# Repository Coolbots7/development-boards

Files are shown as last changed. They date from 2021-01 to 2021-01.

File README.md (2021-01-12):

# Development Boards
PCBs made to test core designs and / or help with rapid prototyping.

# Boards
## ATMega32u4 Development Board (Arduino Micro Equivalent)
Breadboard breakout PCB for an ATMega32u4 8-bit AVR microcontroller.

<p float="left">
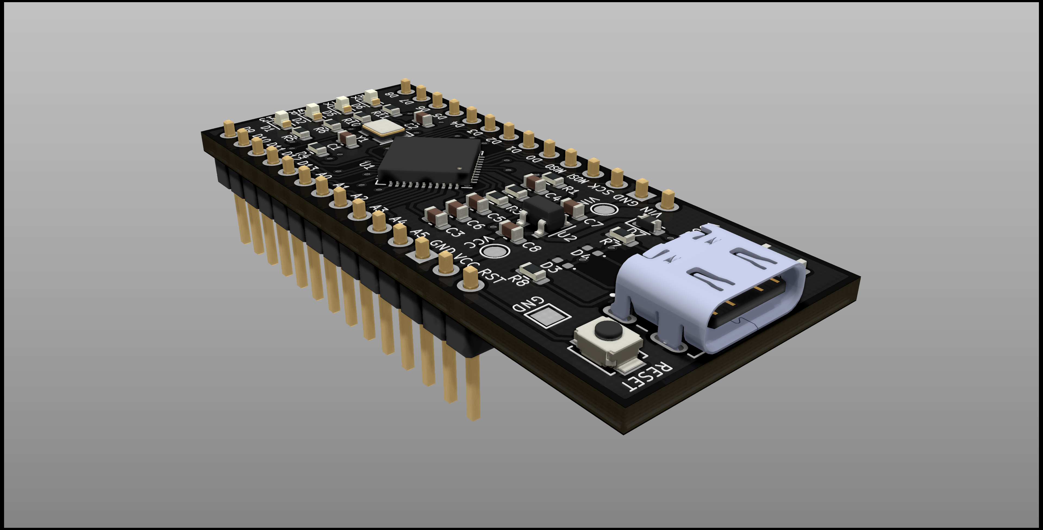
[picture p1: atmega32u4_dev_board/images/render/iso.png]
iso render
 
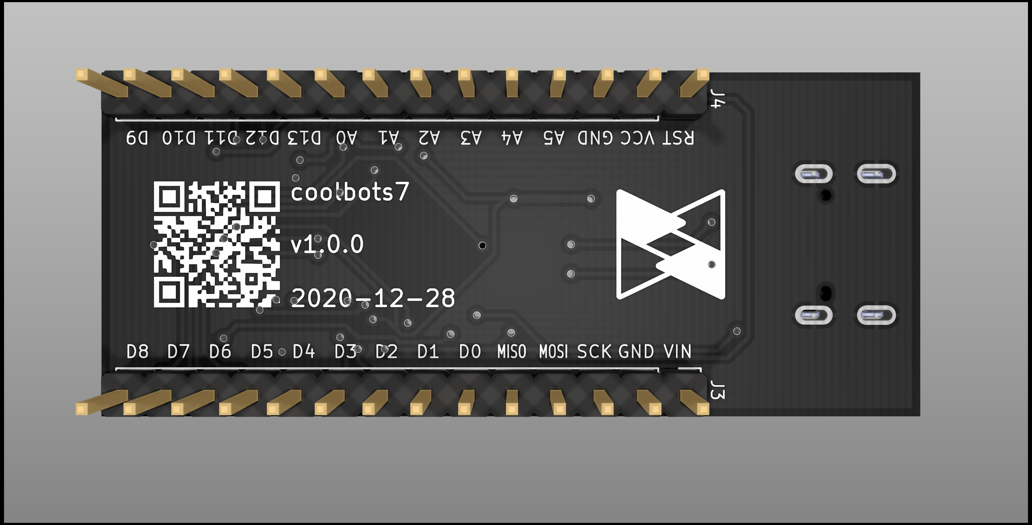
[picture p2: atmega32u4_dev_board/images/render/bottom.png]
bottom render
 
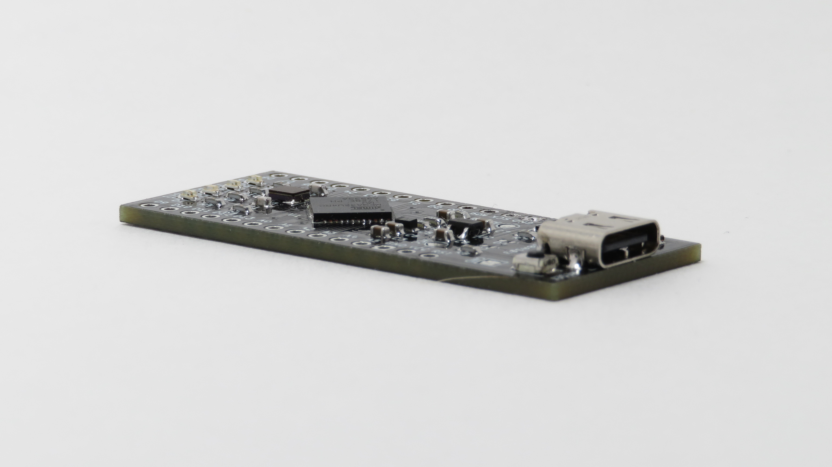
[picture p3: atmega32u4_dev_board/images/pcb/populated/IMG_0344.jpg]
iso populated
 
</p>

### Features:
* USB-C connector for programming and power up to 250mA.
* 5V 500mA linear regulator for external power up to 12VDC.
* Power, TX, RX, and D13 LEDs.
* Pins are labeled on both the top and bottom of the board for easy reference.
  * Note: The pinout is not the same as an actual Arduino Micro

### Bill of Materials:
[Shopping Cart on DigiKey](https://www.digikey.com/short/4ch5mv)

### Future Ideas:
* Ability to construct 3.3V and 5V versions using the same PCB

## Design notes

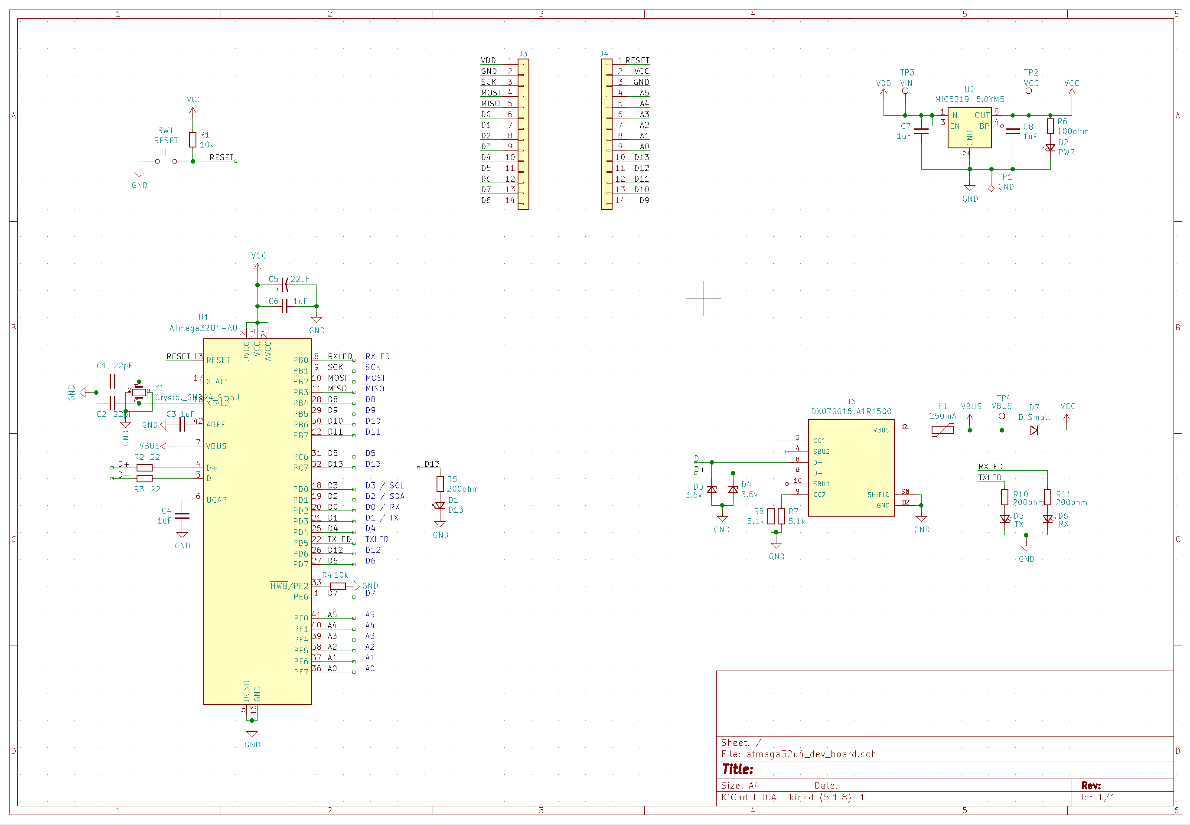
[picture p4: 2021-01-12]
atmega32u4_dev_board/images/schematic/schematic.png

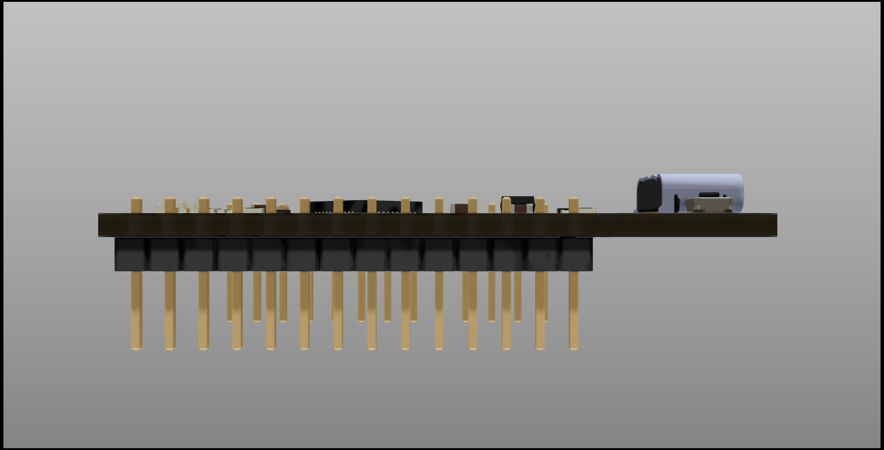
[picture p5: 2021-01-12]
atmega32u4_dev_board/images/render/side.png

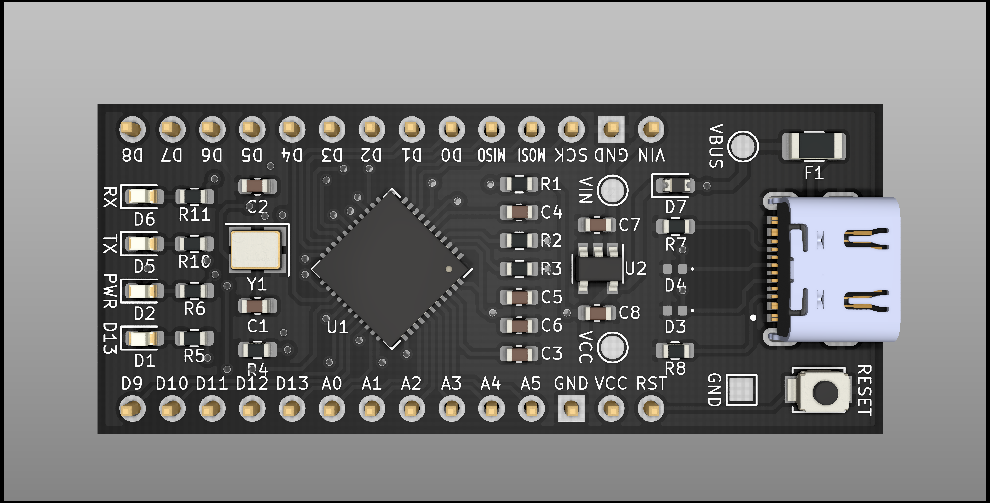
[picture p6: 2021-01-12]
atmega32u4_dev_board/images/render/top.png

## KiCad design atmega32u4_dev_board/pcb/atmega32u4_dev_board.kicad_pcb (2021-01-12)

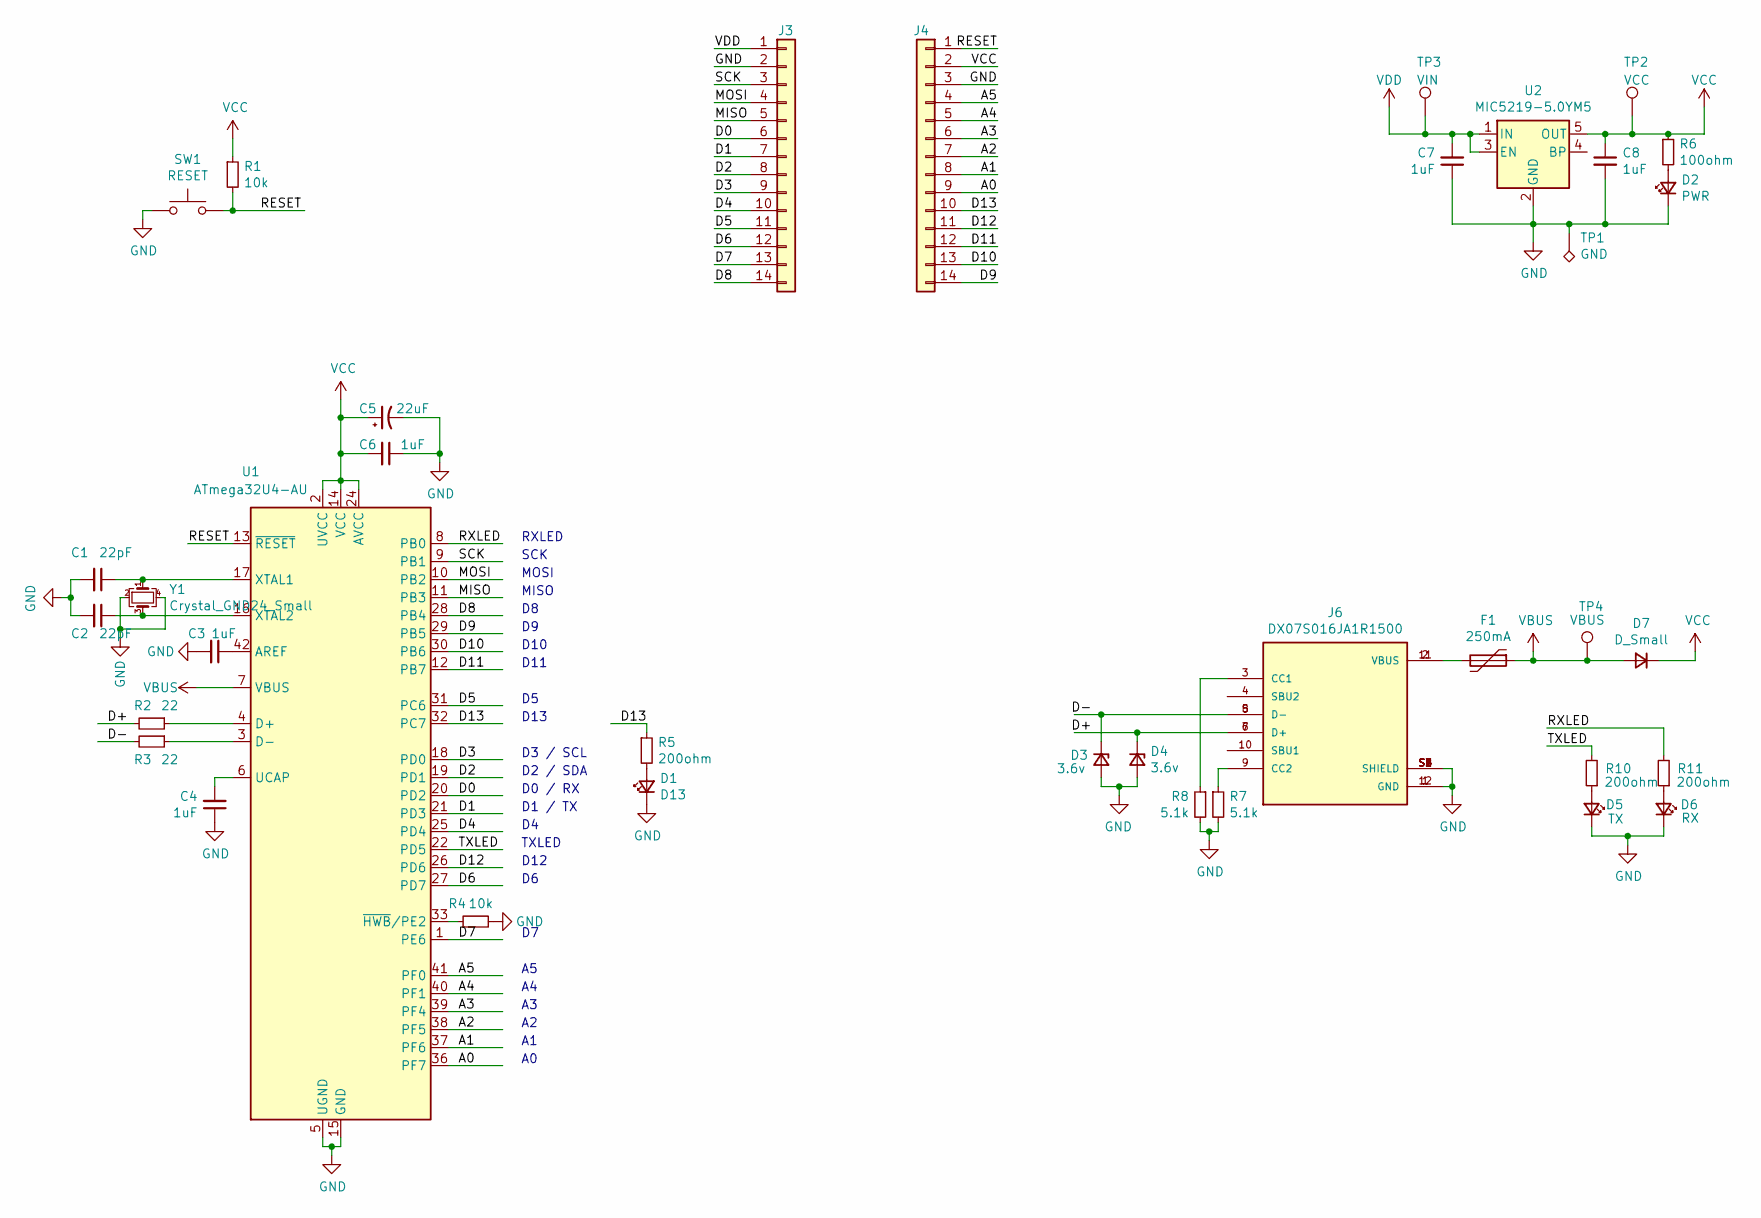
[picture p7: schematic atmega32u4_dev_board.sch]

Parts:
C1, C2: 22pF; C_0603_1608Metric
C3, C4, C6, C7, C8: 1uF; C_0603_1608Metric
C5: 22uF; C_0603_1608Metric
D1: D13; LED_0603_1608Metric
D2: PWR; LED_0603_1608Metric
D3, D4: 3.6v; D_0402_1005Metric
D5: TX; LED_0603_1608Metric
D6: RX; LED_0603_1608Metric
D7: D_Small; D_0603_1608Metric
F1: 250mA; Fuse_1206_3216Metric
J3, J4: Conn_01x14; PinHeader_1x14_P2.54mm_Vertical
J6: DX07S016JA1R1500; JAE_DX07S016JA1R1500; PARTREV 1
R1, R4: 10k; R_0603_1608Metric
R2, R3: 22; R_0603_1608Metric
R5, R10, R11: 200ohm; R_0603_1608Metric
R6: 100ohm; R_0603_1608Metric
R7, R8: 5.1k; R_0603_1608Metric
SW1: RESET; SW_SPST_B3U-1000P
TP1: GND; TestPoint_Pad_1.5x1.5mm
TP2: VCC; TestPoint_Pad_D1.5mm
TP3: VIN; TestPoint_Pad_D1.5mm
TP4: VBUS; TestPoint_Pad_D1.5mm
U1: ATmega32U4-AU; QFN-44-1EP_7x7mm_P0.5mm_EP5.2x5.2mm
U2: MIC5219-5.0YM5; SOT-23-5
Y1: Crystal_GND24_Small; Crystal_SMD_3225-4Pin_3.2x2.5mm

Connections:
/A0: J4.9, U1.36 (PF7)
/A1: J4.8, U1.37 (PF6)
/A2: J4.7, U1.38 (PF5)
/A3: J4.6, U1.39 (PF4)
/A4: J4.5, U1.40 (PF1)
/A5: J4.4, U1.41 (PF0)
/D0: J3.6, U1.20 (PD2)
/D1: J3.7, U1.21 (PD3)
/D2: J3.8, U1.19 (PD1)
/D3: J3.9, U1.18 (PD0)
/D4: J3.10, U1.25 (PD4)
/D5: J3.11, U1.31 (PC6)
/D6: J3.12, U1.27 (PD7)
/D7: J3.13, U1.1 (PE6)
/D8: J3.14, U1.28 (PB4)
/D9: J4.14, U1.29 (PB5)
/D10: J4.13, U1.30 (PB6)
/D11: J4.12, U1.12 (PB7)
/D12: J4.11, U1.26 (PD6)
/D13: J4.10, R5.1, U1.32 (PC7)
/D+: D4.1 (K), J6.6 (D+), J6.7 (D+), R2.2
/D-: D3.1 (K), J6.5 (D-), J6.8 (D-), R3.2
/MISO: J3.5, U1.11 (PB3)
/MOSI: J3.4, U1.10 (PB2)
/RESET: J4.1, R1.2, SW1.2, U1.13 (~RESET)
/RXLED: R11.2, U1.8 (PB0)
/SCK: J3.3, U1.9 (PB1)
/TXLED: R10.2, U1.22 (PD5)
GND: C1.2, C2.2, C3.2, C4.1, C5.2, C6.1, C7.1, C8.2, D1.1 (K), D2.1 (K), D3.2 (A), D4.2 (A), D5.1 (K), D6.1 (K), J3.2, J4.3, J6.1 (GND), J6.12 (GND), J6.S1 (SHIELD), J6.S2 (SHIELD), J6.S3 (SHIELD), J6.S4 (SHIELD), J6.S5 (SHIELD), J6.S6 (SHIELD), R4.2, R7.2, R8.2, SW1.1, TP1.1, U1.5 (UGND), U1.15 (GND), U1.23 (GND), U1.35 (GND), U1.43 (GND), U2.2 (GND), Y1.2, Y1.4
unnamed: C1.1, U1.17 (XTAL1), Y1.1
unnamed: C2.1, U1.16 (XTAL2), Y1.3
unnamed: C3.1, U1.42 (AREF)
unnamed: C4.2, U1.6 (UCAP)
unnamed: D1.2 (A), R5.2
unnamed: D2.2 (A), R6.2
unnamed: D5.2 (A), R10.1
unnamed: D6.2 (A), R11.1
unnamed: F1.2, J6.2 (VBUS), J6.11 (VBUS)
unnamed: J6.3 (CC1), R8.1
unnamed: J6.9 (CC2), R7.1
unnamed: R2.1, U1.4 (D+)
unnamed: R3.1, U1.3 (D-)
unnamed: R4.1, U1.33 (~HWB~/PE2)
VBUS: D7.2 (A), F1.1, TP4.1, U1.7 (VBUS)
VCC: C5.1, C6.2, C8.1, D7.1 (K), J4.2, R1.1, R6.1, TP2.1, U1.2 (UVCC), U1.14 (VCC), U1.24 (AVCC), U1.34 (VCC), U1.44 (AVCC), U2.5 (OUT)
VDD: C7.2, J3.1, TP3.1, U2.1 (IN), U2.3 (EN)

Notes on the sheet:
RXLED
SCK
MOSI
MISO
D3 / SCL
D2 / SDA
D0 / RX
D1 / TX
TXLED
D12
D10
D11
D13

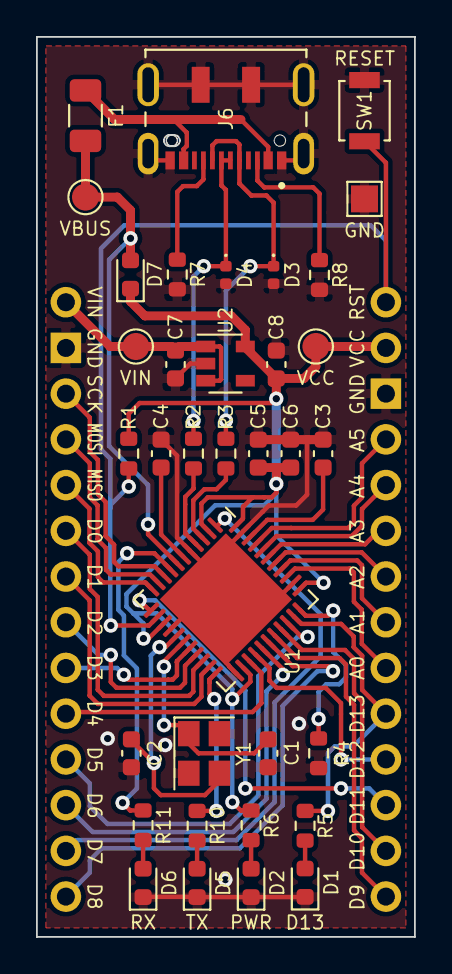
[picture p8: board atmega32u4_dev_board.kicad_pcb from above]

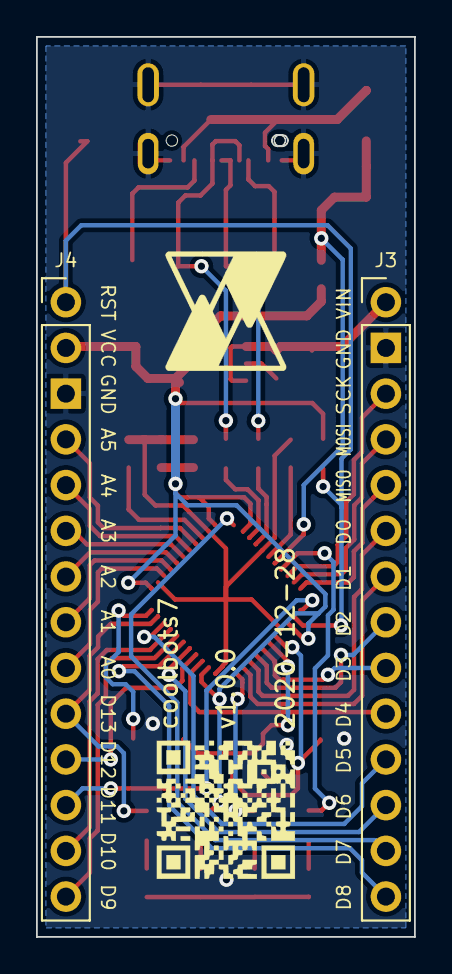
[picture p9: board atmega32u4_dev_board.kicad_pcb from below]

Board: 2 copper layers, 21.0 x 50.0 mm, 37 parts (2 on the bottom side), 46 nets.

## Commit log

2021-01-11 Initial Commit. README and KiCAD gitignore.
2021-01-12 Add atmega32u4 dev board v1.0.0
    [atmega32u4_dev_board-B_Cu.gbr, atmega32u4_dev_board-B_Mask.gbr, atmega32u4_dev_board-B_SilkS.gbr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]
